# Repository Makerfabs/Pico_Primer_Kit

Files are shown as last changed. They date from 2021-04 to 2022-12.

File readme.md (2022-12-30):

# Pico(W) Primer Kit

```c++
/*
Version:		V1.8
Author:			Vincent
Create Date:	2021/4/16
Note:
	2022/12/30	V1.8 Edit Wiki Link
	2022/10/11 	V1.7 Add project11,12
	2022/10/8 	V1.6 Update project10
	2022/9/27 	V1.5 Add PicoW support, add new Mabee CO2
	2022/9/20 	V1.4 Fix dht11 bug.
	2021/7/27 	V1.3 Add WS2812
	2021/5/24 	V1.2 Change IR to Ultar distance sensor.
	2021/5/19 	V1.1 Add 7 display example with MaBee module.
	
*/
```

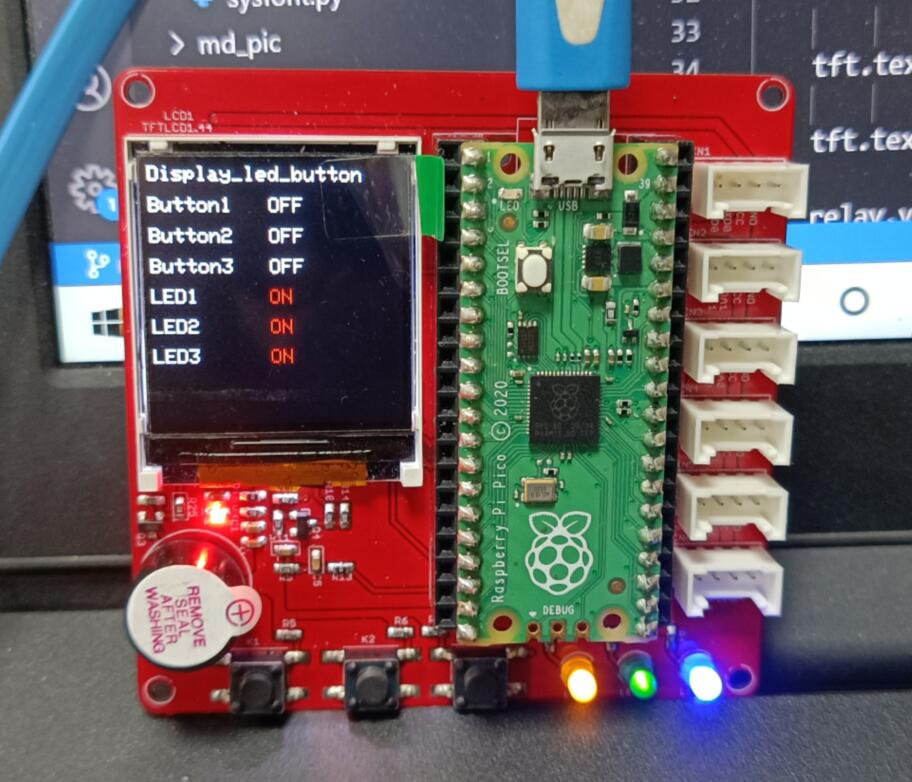
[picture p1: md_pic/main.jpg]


[toc]

# Makerfabs

[Makerfabs home page](https://www.makerfabs.com/)

[Makerfabs Wiki](https://wiki.makerfabs.com/)

# Pico(PicoW) Primer Kit
## Intruduce

### Product Link ：

[Pico Primer Kit for Raspberry PI](https://www.makerfabs.com/raspberry-pi-pico-primer-kit.html)

[Pico W Primer Kit for Raspberry PI](https://www.makerfabs.com/pico-w-primer-kit-for-raspberry-pi.html)

### Wiki Link : 

[Pico W_Primer_kit](https://wiki.makerfabs.com/Pico_W_Primer_Kit.html)

Pico Primer Kit is the development shield of Pi Pico. It has ST7735 color screen, 3 LED lights and 3 buttons. There are multiple SPI, I2C, UART, GPIO interfaces.
Kit contains a number of MBEE series modules. Such as potentiometer, DHT11, MPU6050, relay and other modules.

**Now that we have a new kit for Pico W, we have replaced the 8266 module with Mabee CO2.**

Most routines are compatible, the only differences are those related to WiFi.

## Feature

- RP2040 microcontroller chip designed by Raspberry Pi in the United Kingdom
- Dual-core Arm Cortex M0+ processor, the flexible clock running up to 133 MHz
- 264KB of SRAM, and 2MB of onboard Flash memory
- Castellated module allows soldering direct to carrier boards
- USB 1.1 with device and host support
- Low-power sleep and dormant modes
- Drag-and-drop programming using mass storage over USB
- 26 × multi-function GPIO pins
- 2 × SPI, 2 × I2C, 2 × UART, 3 × 12-bit ADC, 16 × controllable PWM channels
- Accurate clock and timer on-chip
- Temperature sensor
- Accelerated floating-point libraries on-chip
- 8 × Programmable I/O (PIO) state machines for custom peripheral support

### Front:

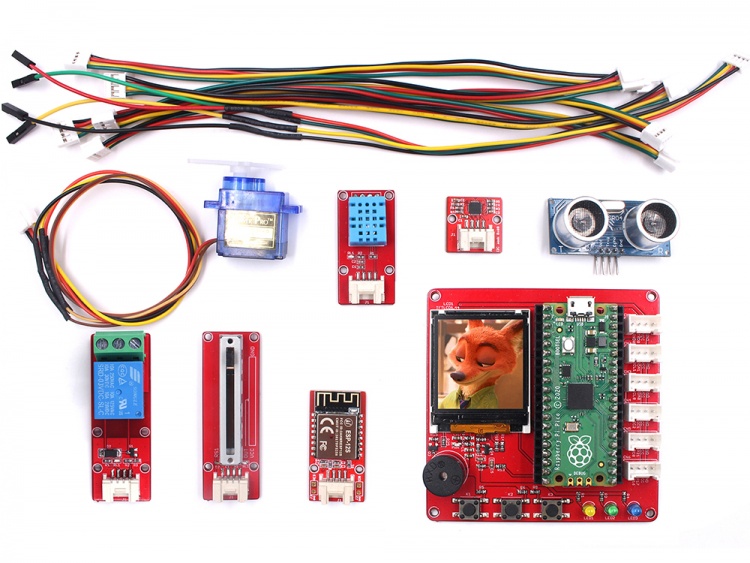
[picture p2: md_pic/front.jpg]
front


### Back:
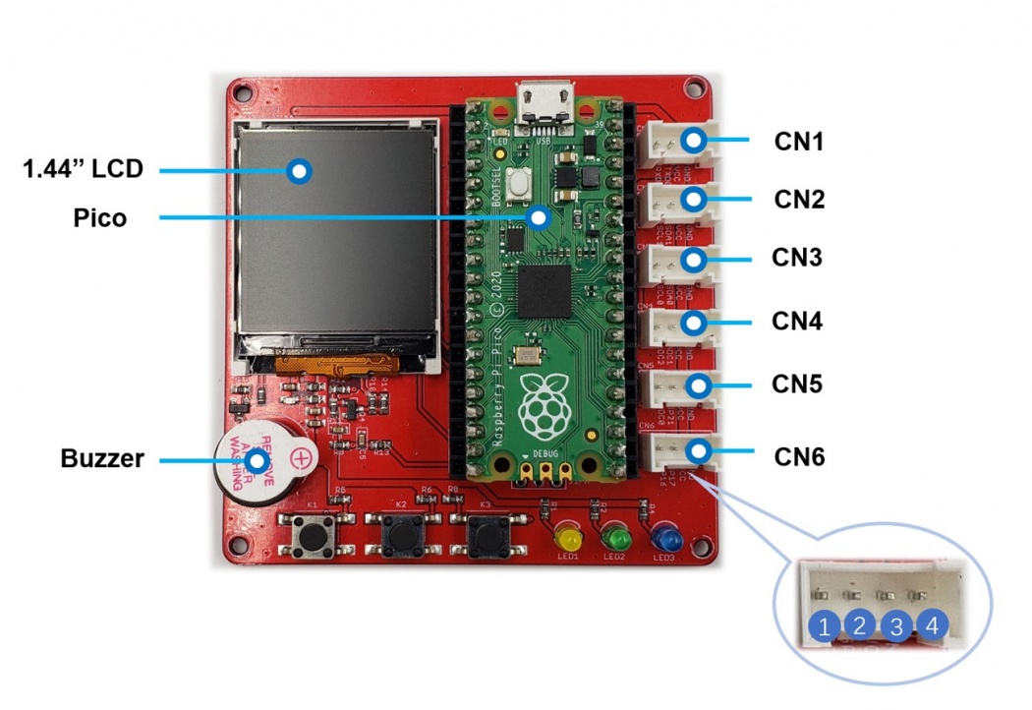
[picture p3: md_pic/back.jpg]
back


# Example
## Equipment list

- Pico Primer Kit
- Pi Pico
- MBee modules

## How To Use?

Attention, all code depends on MicroPython v1.19.1 on 2022-08-19

**Subsequent code may not run due to MicroPython version updates. We provide two firmware.**

- Pico		:	rp2-pico-20220618-v1.19.1.uf2

- PicoW	:	rp2-pico-w-20220819-unstable-v1.19.1-298-gc616721b1.uf2

Because PicoW MicroPython has not been officially released, so the driver of the sensor, subject to the Pico.

**If you have any questions，such as how to install the development board, how to download the code.**

**Please refer to :[Get Started with MicroPython on Raspberry Pi Pico](https://hackspace.raspberrypi.org/books/micropython-pico)**

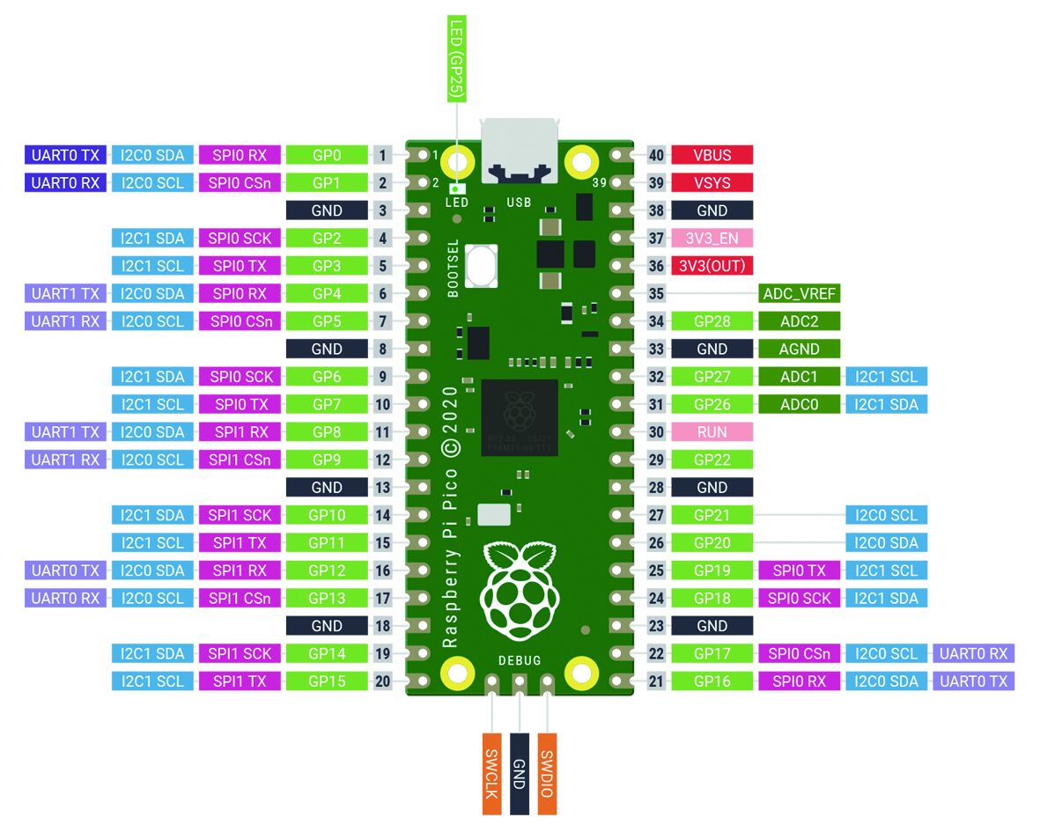
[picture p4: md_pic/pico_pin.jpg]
pin


## V1.2 Project

### project-1-display_led_button.py

Control onboard leds via buttons.
And display status on TFT screen.
Don't need any module

### project-2-leveling.py

Simple graphic level, read inclination angle with MPU6050.
Insert MaBee MPU6050 to CN3

### project-3-adc_display.py

The voltage value of the read slide potentimeter is displayed on the screen
Insert MaBee Slide Potentimeter to CN5

### project-4-weather_8266.py

Connect to WiFi through ESP8266 module and get the weather.
Insert MaBee 8266 to CN1
API from "api.openweathermap.org" is not stable, please try more and pay attention to the serial port information.

### project-5-temperature .py

The temperature and humidity are obtained through DHT11 and displayed on the screen
Insert MaBee DHT11 to CN6

### ~~project-6-ir_distance.py~~

~~The distance is captured by a Sharpir sensor and displayed on the screen~~
~~Insert SharpIR to CN5~~

### project-6-HC-SR04_distance.py

The distance is captured by a HC-SR04 Ultra sensor and displayed on the screen
Insert SharpIR to CN6

### project-7-servo_control.py

Use button control servo and MaBee relay
Insert Servo to CN6
Insert MaBee Relay to CN5

### project-8-ws2812.py
Insert WS2812 to CN6

### project-9-weather.py

Instead of Project 4 without 8266.

**Only for Pico W**

### project-10-CO2.py

Mabee CO2 message display and run a webserver.

Insert Mabee CO2 to CN3, sda to GPIO8, scl to GPIO9

Need change WiFi config in code.

```python
ssid = 'Makerfabs'
password = '20160704'
```

### project-11-thingspeak.py

A simple example is sending data to ThingSpeak. 

Please replace the Wifi information and Thingspeak interface with the user's own.

**Only for Pico W**

### project-12-PIR_detection.py

PIR induction Demo, when the sensor detects the human body after alarm.

## Other test file

All files starting with Test are used by engineers and are not guaranteed to be completely correct. 

But it has some reference value.

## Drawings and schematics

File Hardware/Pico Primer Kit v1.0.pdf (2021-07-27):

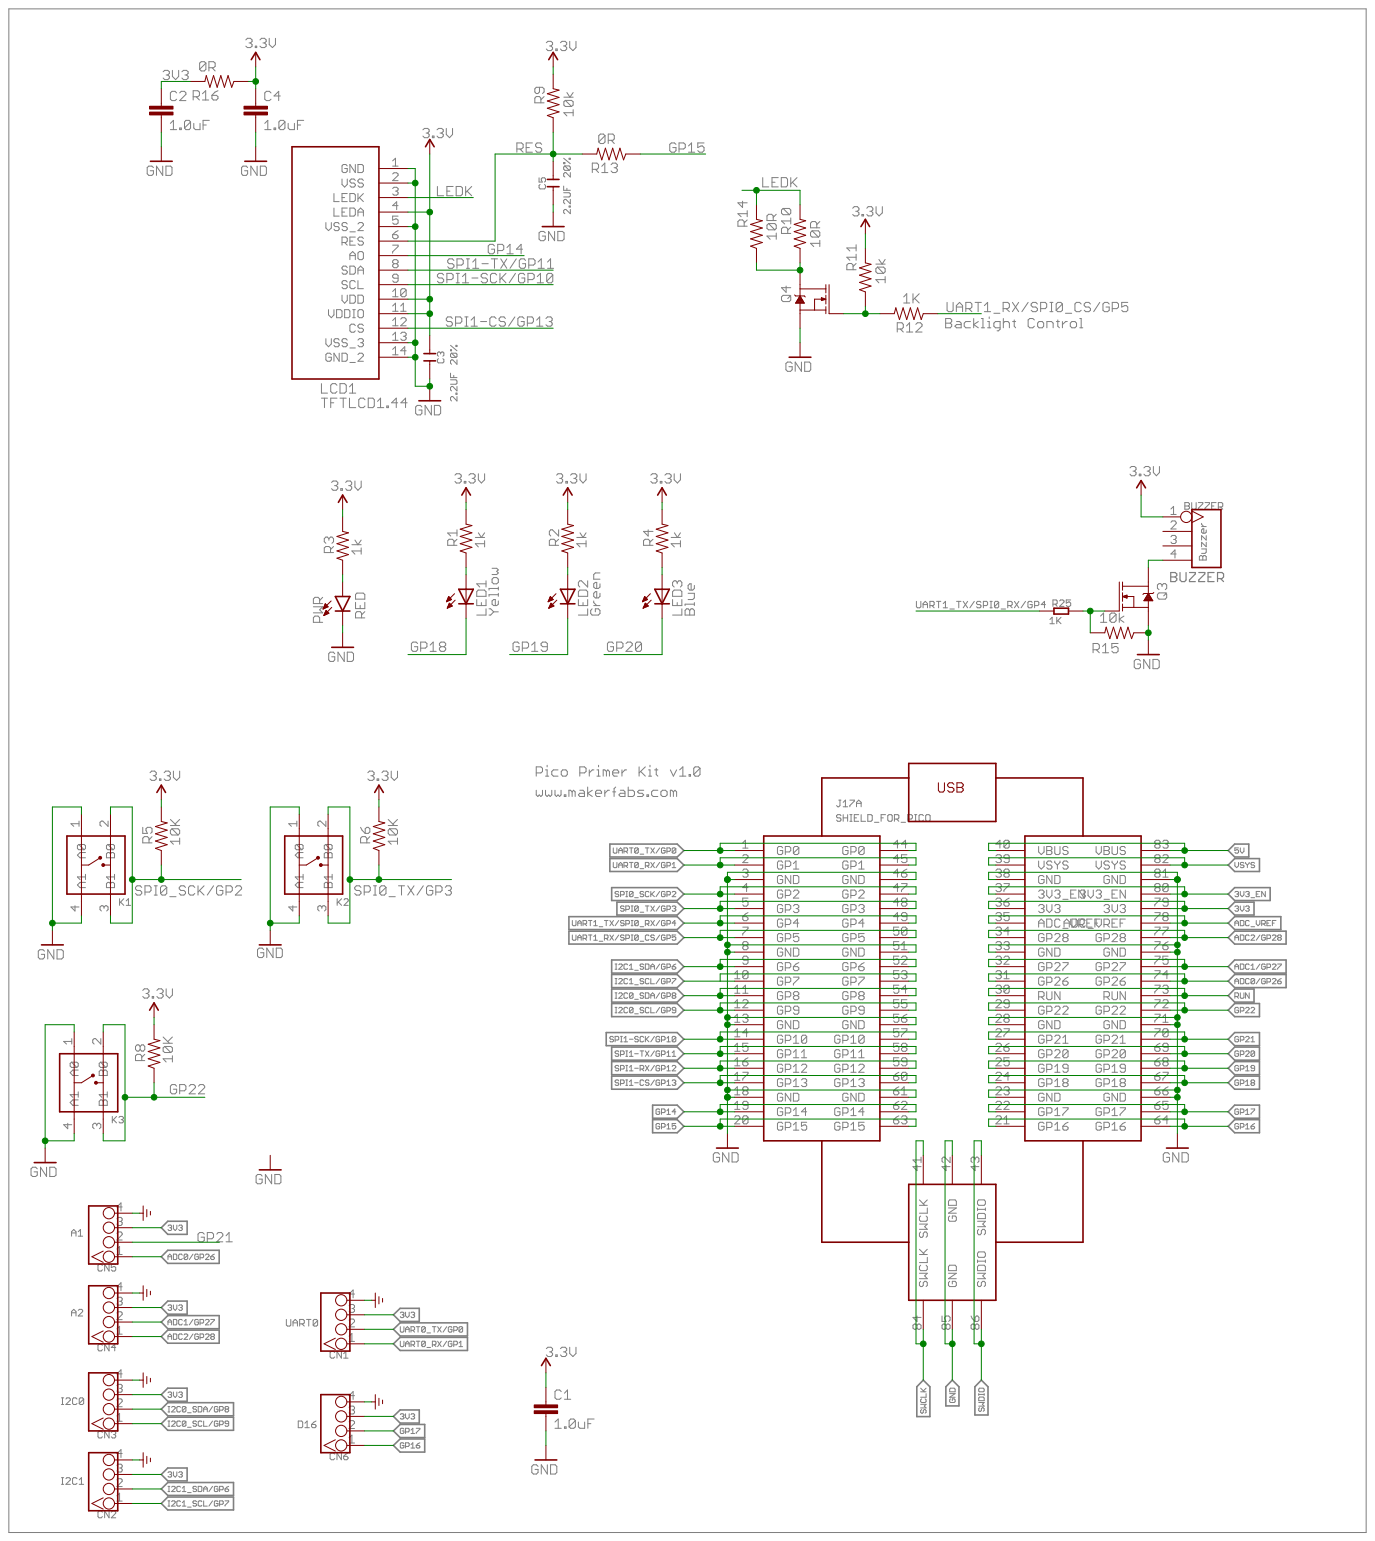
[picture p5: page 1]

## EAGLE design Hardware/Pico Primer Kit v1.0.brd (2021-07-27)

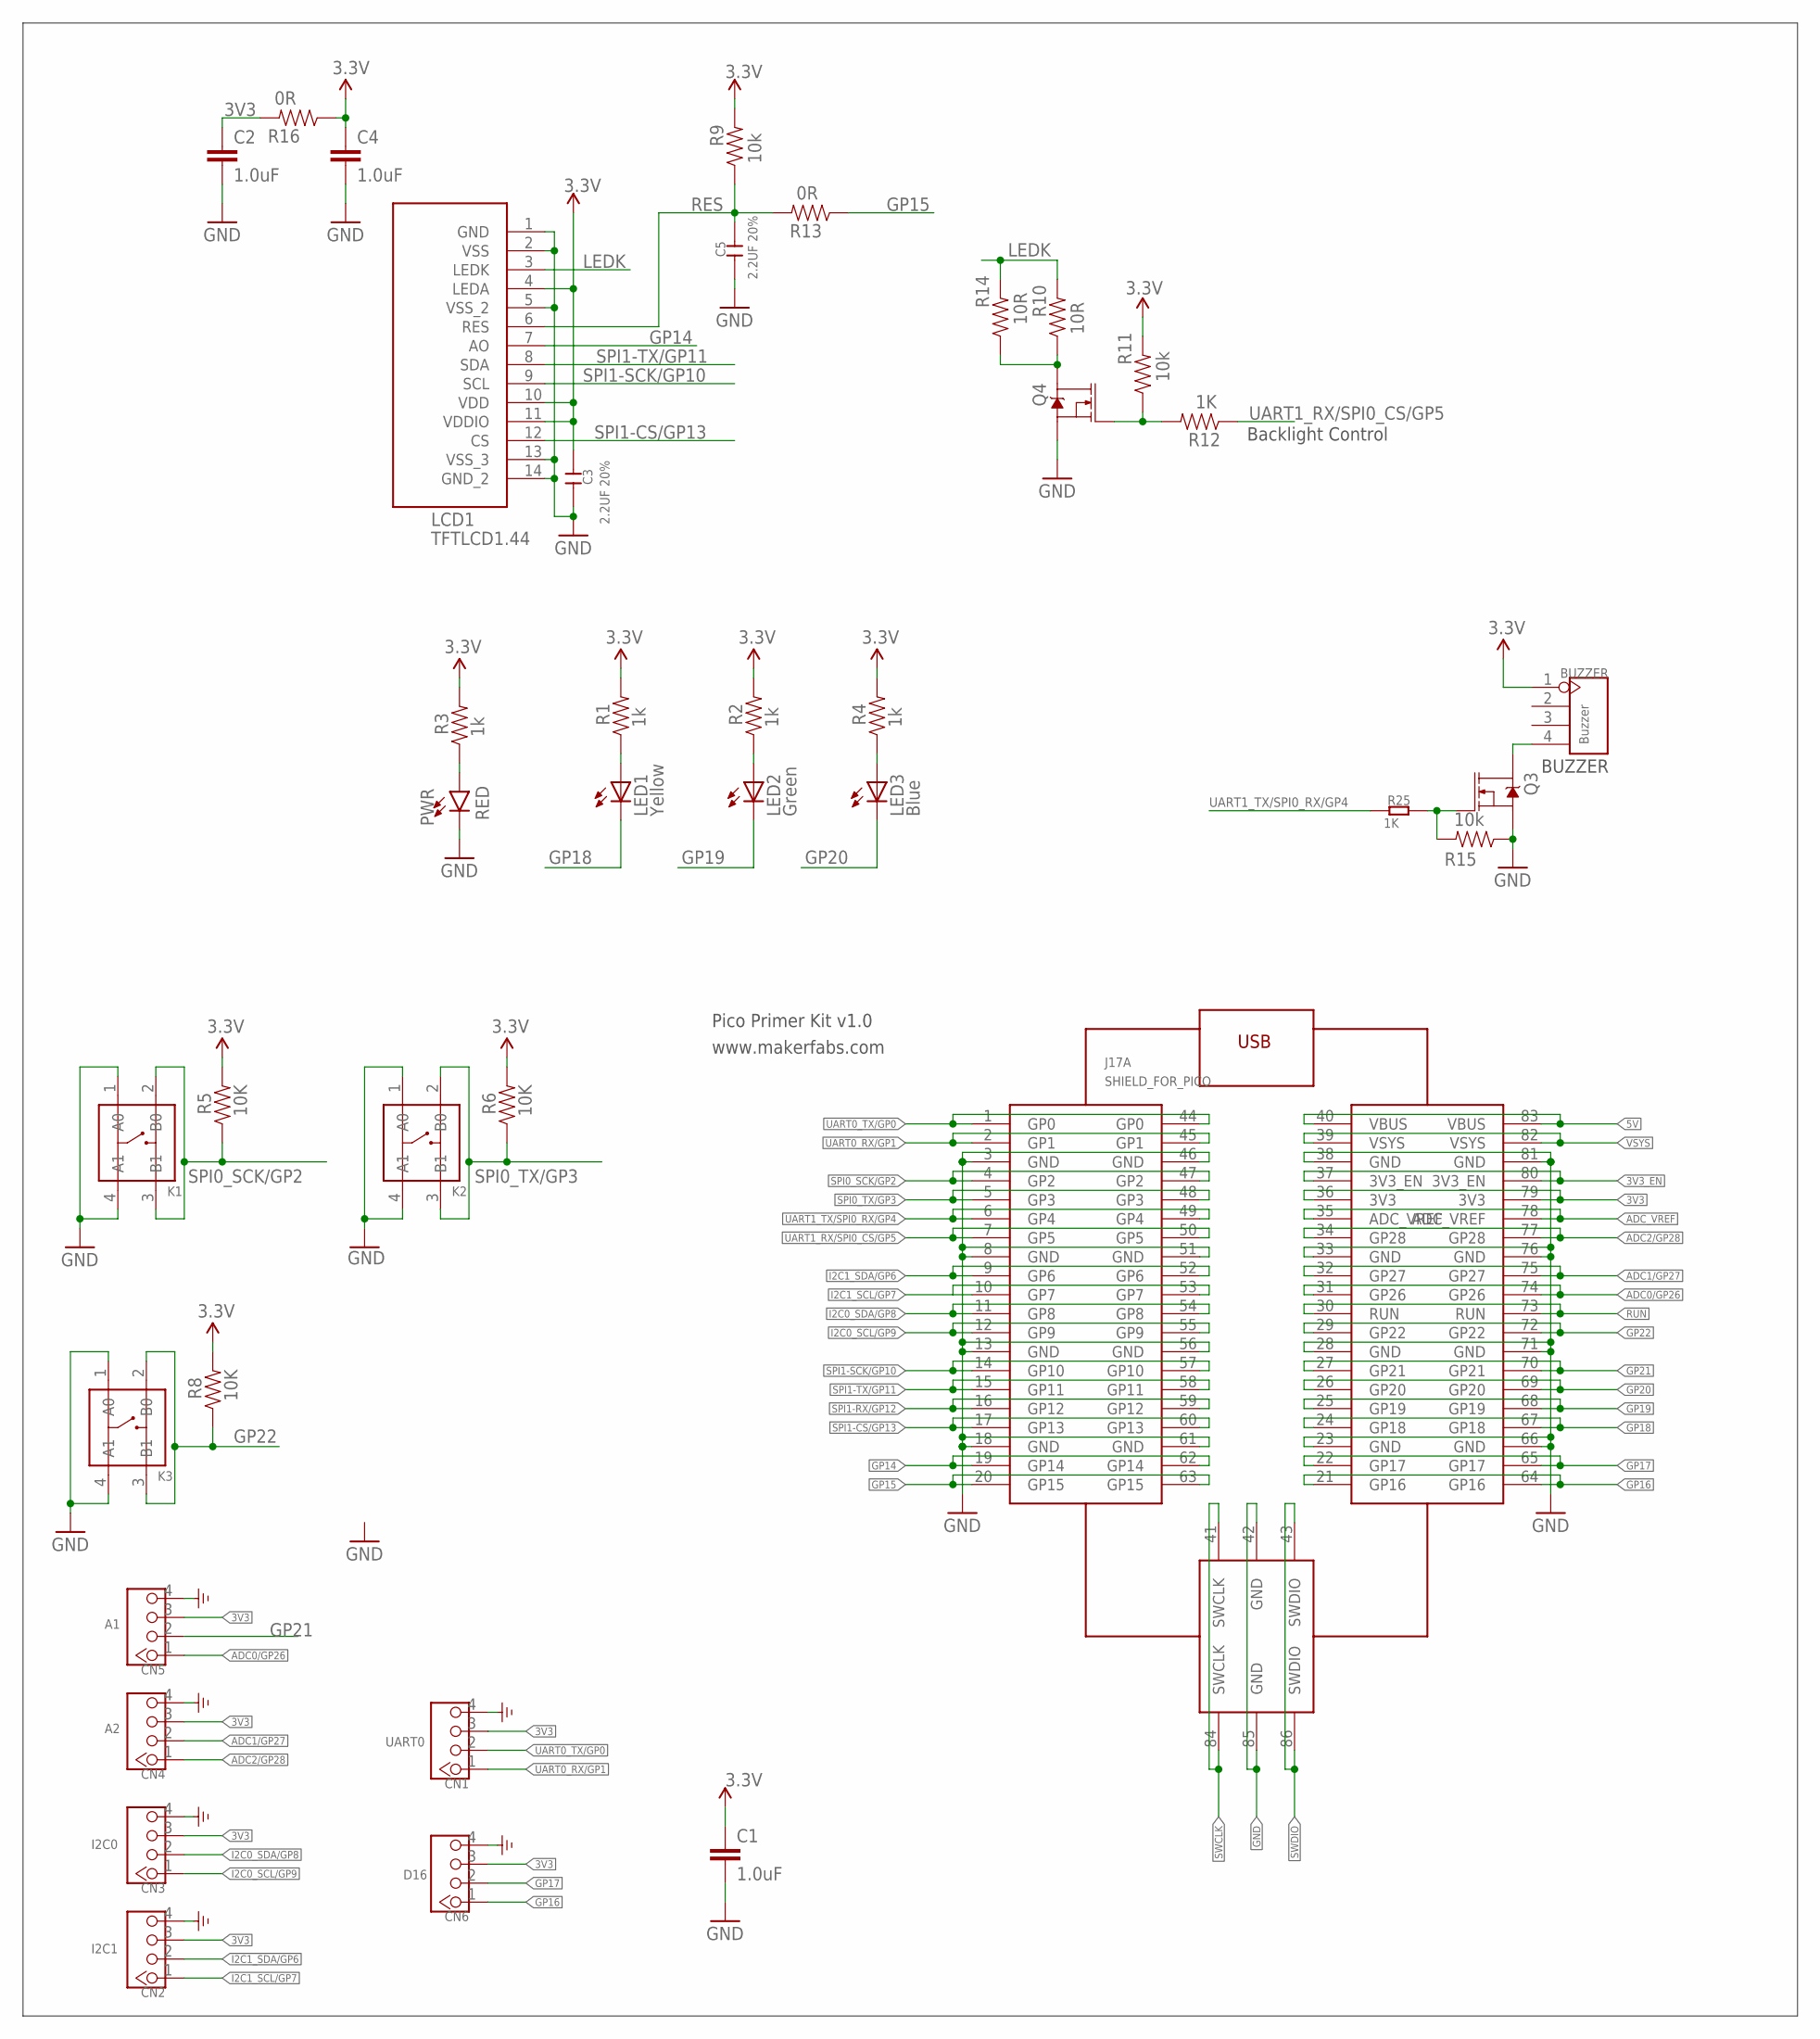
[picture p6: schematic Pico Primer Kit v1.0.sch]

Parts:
BUZZER: Buzzer; 4P-65/35ROUND
C1, C2, C4: 1.0uF; 0603
C3, C5: 2.2UF 20%; 0603
CN1: UART0; 4P-2.0
CN2: I2C1; 4P-2.0
CN3: I2C0; 4P-2.0
CN4: A2; 4P-2.0
CN5: A1; 4P-2.0
CN6: D16; 4P-2.0
J17A: SHIELD_FOR_PICO
K1, K2, K3: BUTTON-4P-3100010P1; 4P-SMD-6.0X6.0X5.0H
LCD1: TFTLCD1.44
LED1: Yellow; LED3MM
LED2: Green; LED3MM
LED3: Blue; LED3MM
PWR: RED; LED-0603
Q3, Q4: 220mA/50V/3.5Ω; SOT23-3
R1, R2, R3, R4: 1k; 0603
R5, R6, R8: 10K; 0603
R9, R11, R15: 10k; 0603
R10, R14: 10R; 0603
R12: 1K; 0603
R13, R16: 0R; 0603
R25: 1K; R0603

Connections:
3.3V: BUZZER.1, C1.1, C3.2, C4.1, LCD1.4 (LEDA), LCD1.10 (VDD), LCD1.11 (VDDIO), R1.2, R2.2, R3.2, R4.2, R5.2, R6.2, R8.2, R9.2, R11.2, R16.1
3V3: C2.1, CN1.3, CN2.3, CN3.3, CN4.3, CN5.3, CN6.3, J17A.36 (3V3), J17A.79 (3V3), R16.2
3V3_EN: J17A.37 (3V3_EN), J17A.80 (3V3_EN)
5V: J17A.40 (VBUS), J17A.83 (VBUS)
ADC0/GP26: CN5.1, J17A.31 (GP26), J17A.74 (GP26)
ADC1/GP27: CN4.2, J17A.32 (GP27), J17A.75 (GP27)
ADC2/GP28: CN4.1, J17A.34 (GP28), J17A.77 (GP28)
ADC_VREF: J17A.35 (ADC_VREF), J17A.78 (ADC_VREF)
GND: C1.2, C2.2, C3.1, C4.2, C5.1, CN1.4, CN2.4, CN3.4, CN4.4, CN5.4, CN6.4, J17A.3 (GND), J17A.8 (GND), J17A.13 (GND), J17A.18 (GND), J17A.23 (GND), J17A.28 (GND), J17A.33 (GND), J17A.38 (GND), J17A.42 (GND), J17A.46 (GND), J17A.51 (GND), J17A.56 (GND), J17A.61 (GND), J17A.66 (GND), J17A.71 (GND), J17A.76 (GND), J17A.81 (GND), J17A.85 (GND), K1.1 (A0), K1.4 (A1), K2.1 (A0), K2.4 (A1), K3.1 (A0), K3.4 (A1), LCD1.1 (GND), LCD1.2 (VSS), LCD1.5 (VSS_2), LCD1.13 (VSS_3), LCD1.14 (GND_2), PWR.C, Q3.2 (S), Q4.2 (S), R15.1
GP14: J17A.19 (GP14), J17A.62 (GP14), LCD1.7 (AO)
GP15: J17A.20 (GP15), J17A.63 (GP15), R13.1
GP16: CN6.1, J17A.21 (GP16), J17A.64 (GP16)
GP17: CN6.2, J17A.22 (GP17), J17A.65 (GP17)
GP18: J17A.24 (GP18), J17A.67 (GP18), LED1.K (C)
GP19: J17A.25 (GP19), J17A.68 (GP19), LED2.K (C)
GP20: J17A.26 (GP20), J17A.69 (GP20), LED3.K (C)
GP21: CN5.2, J17A.27 (GP21), J17A.70 (GP21)
GP22: J17A.29 (GP22), J17A.72 (GP22), K3.2 (B0), K3.3 (B1), R8.1
I2C0_SCL/GP9: CN3.1, J17A.12 (GP9), J17A.55 (GP9)
I2C0_SDA/GP8: CN3.2, J17A.11 (GP8), J17A.54 (GP8)
I2C1_SCL/GP7: CN2.1, J17A.10 (GP7), J17A.53 (GP7)
I2C1_SDA/GP6: CN2.2, J17A.9 (GP6), J17A.52 (GP6)
LEDK: LCD1.3 (LEDK), R10.2, R14.2
unnamed: LED1.A, R1.1
unnamed: PWR.A, R3.1
unnamed: Q4.3 (D), R10.1, R14.1
unnamed: Q4.1 (G), R11.1, R12.2
unnamed: LED2.A, R2.1
unnamed: LED3.A, R4.1
unnamed: BUZZER.4, Q3.3 (D)
unnamed: Q3.1 (G), R15.2, R25.2
RES: C5.2, LCD1.6 (RES), R9.1, R13.2
RUN: J17A.30 (RUN), J17A.73 (RUN)
SPI0_SCK/GP2: J17A.4 (GP2), J17A.47 (GP2), K1.2 (B0), K1.3 (B1), R5.1
SPI0_TX/GP3: J17A.5 (GP3), J17A.48 (GP3), K2.2 (B0), K2.3 (B1), R6.1
SPI1-CS/GP13: J17A.17 (GP13), J17A.60 (GP13), LCD1.12 (CS)
SPI1-RX/GP12: J17A.16 (GP12), J17A.59 (GP12)
SPI1-SCK/GP10: J17A.14 (GP10), J17A.57 (GP10), LCD1.9 (SCL)
SPI1-TX/GP11: J17A.15 (GP11), J17A.58 (GP11), LCD1.8 (SDA)
SWCLK: J17A.41 (SWCLK), J17A.84 (SWCLK)
SWDIO: J17A.43 (SWDIO), J17A.86 (SWDIO)
UART0_RX/GP1: CN1.1, J17A.2 (GP1), J17A.45 (GP1)
UART0_TX/GP0: CN1.2, J17A.1 (GP0), J17A.44 (GP0)
UART1_RX/SPI0_CS/GP5: J17A.7 (GP5), J17A.50 (GP5), R12.1
UART1_TX/SPI0_RX/GP4: J17A.6 (GP4), J17A.49 (GP4), R25.1
VSYS: J17A.39 (VSYS), J17A.82 (VSYS)

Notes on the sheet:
Pico Primer Kit v1.0
www.makerfabs.com
BUZZER
Backlight Control

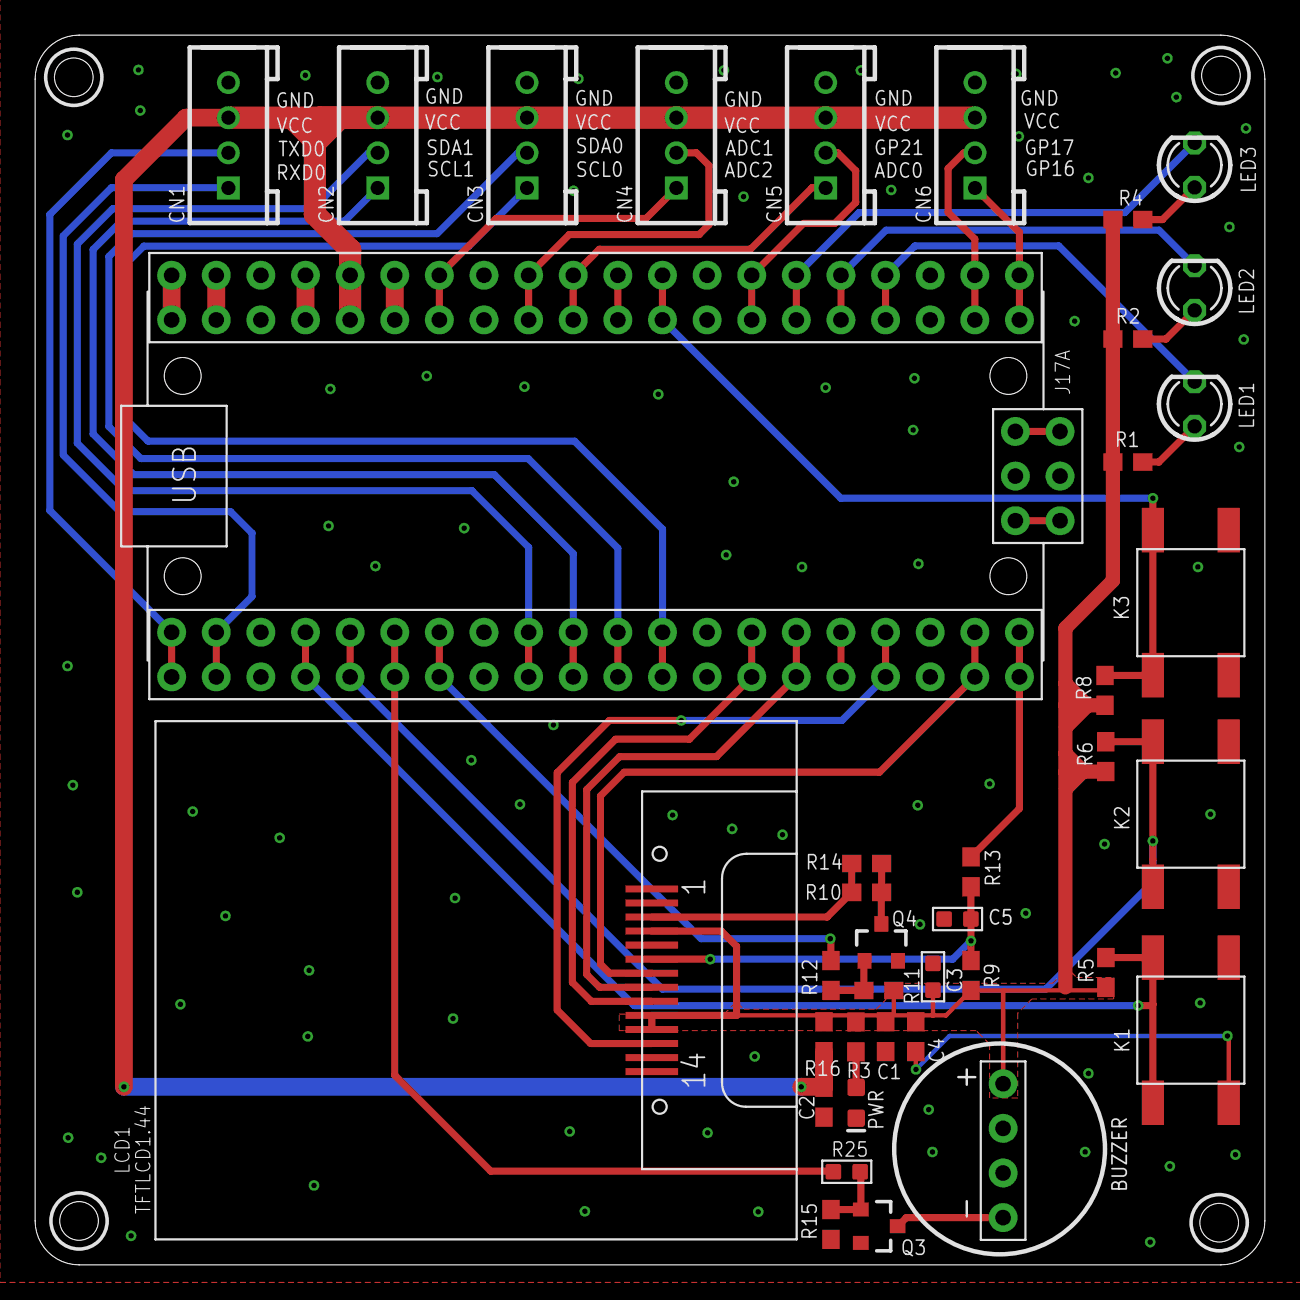
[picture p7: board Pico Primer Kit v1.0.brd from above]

Board: 2 copper layers, 70.0 x 70.0 mm, 40 parts (1 on the bottom side), 46 nets.

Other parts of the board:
U$1: MAKERFABS_0.3

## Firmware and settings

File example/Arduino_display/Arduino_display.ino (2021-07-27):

#include <Adafruit_GFX.h>    // Core graphics library
#include <Adafruit_ST7735.h> // Hardware-specific library for ST7735
#include <SPI.h>

#include "a1.h"
#include "pic1.h"
#include "pic2.h"

#define TFT_CS 13
#define TFT_RST 15 // Or set to -1 and connect to Arduino RESET pin
#define TFT_DC 14

#define SPI_MOSI 11
#define SPI_MISO 12
#define SPI_SCK 10

Adafruit_ST7735 tft = Adafruit_ST7735(TFT_CS, TFT_DC, TFT_RST);

void setup(void)
{
    Serial.begin(115200);
    Serial.print(F("Hello! ST77xx TFT Test"));

    SPI = MbedSPI(SPI_MISO, SPI_MOSI, SPI_SCK);

    // OR use this initializer (uncomment) if using a 1.44" TFT:
    tft.initR(INITR_144GREENTAB); // Init ST7735R chip, green tab

    Serial.println(F("Initialized"));

    tft.fillScreen(ST77XX_BLACK);
}

void loop()
{
    //Show logo
    tft.drawRGBBitmap(0, 0, a1, 128, 128);
    delay(3000);
    tft.drawRGBBitmap(0, 0, pic1, 128, 128);
    delay(3000);
    tft.drawRGBBitmap(0, 0, pic2, 128, 128);
    delay(3000);
}

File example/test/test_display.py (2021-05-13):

# Our supplier changed the 1.8" display slightly after Jan 10, 2012
# so that the alignment of the TFT had to be shifted by a few pixels
# this just means the init code is slightly different. Check the
# color of the tab to see which init code to try. If the display is
# cut off or has extra 'random' pixels on the top & left, try the
# other option!
# If you are seeing red and green color inversion, use Black Tab
# If your TFT's plastic wrap has a Black Tab, use the following:
#  tft.initR(INITR_BLACKTAB);   // initialize a ST7735S chip, black tab
# If your TFT's plastic wrap has a Red Tab, use the following:
# tft.initR(INITR_REDTAB);   // initialize a ST7735R chip, red tab
# If your TFT's plastic wrap has a Green Tab, use the following:
# tft.initR(INITR_GREENTAB); // initialize a ST7735R chip, green tab


from ST7735 import TFT
from sysfont import sysfont
from machine import SPI, Pin
import time
import math


spi = SPI(1, baudrate=20000000, polarity=0, phase=0,
          sck=Pin(10), mosi=Pin(11), miso=None)
# def __init__( self, spi, aDC, aReset, aCS) :
tft = TFT(spi, 14, 15, 13)

tft.initg()
tft.rgb(True)


def testlines(color):
    tft.fill(TFT.BLACK)
    for x in range(0, tft.size()[0], 6):
        tft.line((0, 0), (x, tft.size()[1] - 1), color)
    for y in range(0, tft.size()[1], 6):
        tft.line((0, 0), (tft.size()[0] - 1, y), color)

    tft.fill(TFT.BLACK)
    for x in range(0, tft.size()[0], 6):
        tft.line((tft.size()[0] - 1, 0), (x, tft.size()[1] - 1), color)
    for y in range(0, tft.size()[1], 6):
        tft.line((tft.size()[0] - 1, 0), (0, y), color)

    tft.fill(TFT.BLACK)
    for x in range(0, tft.size()[0], 6):
        tft.line((0, tft.size()[1] - 1), (x, 0), color)
    for y in range(0, tft.size()[1], 6):
        tft.line((0, tft.size()[1] - 1), (tft.size()[0] - 1, y), color)

    tft.fill(TFT.BLACK)
    for x in range(0, tft.size()[0], 6):
        tft.line((tft.size()[0] - 1, tft.size()[1] - 1), (x, 0), color)
    for y in range(0, tft.size()[1], 6):
        tft.line((tft.size()[0] - 1, tft.size()[1] - 1), (0, y), color)


def testfastlines(color1, color2):
    tft.fill(TFT.BLACK)
    for y in range(0, tft.size()[1], 5):
        tft.hline((0, y), tft.size()[0], color1)
    for x in range(0, tft.size()[0], 5):
        tft.vline((x, 0), tft.size()[1], color2)


# def testgamerects(color):
 #   tft.fill(TFT.WHITE) ## How is this screen not GameEngine

  #  for i in range(game.height):
   #     for j in range(game.width):
        # OK need shapes in gameEngine
       #    TFT.rect(screen, GRAY, [
        #                    game.x + game.zoom * j, game.y + game.zoom * i, game.zoom, game.zoom], 1)
        #   if game.field[i][j] > 0:
        #    TFT.rect(screen, colors[game.field[i][j]],
        #                    [game.x + game.zoom * j + 1, game.y + game.zoom * i + 1, game.zoom - 2, game.zoom - 1])


def testdrawrects(color):
    tft.fill(TFT.BLACK)
    for x in range(0, tft.size()[0], 6):
        tft.rect((tft.size()[0]//2 - x//2, tft.size()
                  [1]//2 - x/2), (x, x), color)


def testfillrects(color1, color2):
    tft.fill(TFT.BLACK)
    for x in range(tft.size()[0], 0, -6):
        tft.fillrect((tft.size()[0]//2 - x//2,
                      tft.size()[1]//2 - x/2), (x, x), color1)
        tft.rect((tft.size()[0]//2 - x//2, tft.size()
                  [1]//2 - x/2), (x, x), color2)


def testfillcircles(radius, color):
    for x in range(radius, tft.size()[0], radius * 2):
        for y in range(radius, tft.size()[1], radius * 2):
            tft.fillcircle((x, y), radius, color)


def testdrawcircles(radius, color):
    for x in range(0, tft.size()[0] + radius, radius * 2):
        for y in range(0, tft.size()[1] + radius, radius * 2):
            tft.circle((x, y), radius, color)


def testtriangles():
    tft.fill(TFT.BLACK)
    color = 0xF800
    w = tft.size()[0] // 2
    x = tft.size()[1] - 1
    y = 0
    z = tft.size()[0]
    for t in range(0, 15):
        tft.line((w, y), (y, x), color)
        tft.line((y, x), (z, x), color)
        tft.line((z, x), (w, y), color)
        x -= 4
        y += 4
        z -= 4
        color += 100


def testroundrects():
    tft.fill(TFT.BLACK)
    color = 100
    for t in range(5):
        x = 0
        y = 0
        w = tft.size()[0] - 2
        h = tft.size()[1] - 2
        for i in range(17):
            tft.rect((x, y), (w, h), color)
            x += 2
            y += 3
            w -= 4
            h -= 6
            color += 1100
        color += 100


def tftprinttest():
    tft.fill(TFT.BLACK)
    v = 30
    tft.text((0, v), "Hello World!", TFT.RED, sysfont, 1, nowrap=True)
    v += sysfont["Height"]
    tft.text((0, v), "Hello World!", TFT.YELLOW, sysfont, 2, nowrap=True)
    v += sysfont["Height"] * 2
    tft.text((0, v), "Hello World!", TFT.GREEN, sysfont, 3, nowrap=True)
    v += sysfont["Height"] * 3
    tft.text((0, v), str(1234.567), TFT.BLUE, sysfont, 4, nowrap=True)
    time.sleep_ms(1500)
    tft.fill(TFT.BLACK)
    v = 0
    tft.text((0, v), "Hello World!", TFT.RED, sysfont)
    v += sysfont["Height"]
    tft.text((0, v), str(math.pi), TFT.GREEN, sysfont)
    v += sysfont["Height"]
    tft.text((0, v), " Want pi?", TFT.GREEN, sysfont)
    v += sysfont["Height"] * 2
    tft.text((0, v), hex(8675309), TFT.GREEN, sysfont)
    v += sysfont["Height"]
    tft.text((0, v), " Print HEX!", TFT.GREEN, sysfont)
    v += sysfont["Height"] * 2
    tft.text((0, v), "Sketch has been", TFT.WHITE, sysfont)
    v += sysfont["Height"]
    tft.text((0, v), "running for: ", TFT.WHITE, sysfont)
    v += sysfont["Height"]
    tft.text((0, v), str(time.ticks_ms() / 1000), TFT.PURPLE, sysfont)
    v += sysfont["Height"]
    tft.text((0, v), " seconds.", TFT.WHITE, sysfont)
    tft.fill(TFT.BLACK)
    tft.text((0, 0), "Lorem ipsum dolor sit amet, consectetur adipiscing elit. Curabitur adipiscing ante sed nibh tincidunt feugiat. Maecenas enim massa, fringilla sed malesuada et, malesuada sit amet turpis. Sed porttitor neque ut ante pretium vitae malesuada nunc bibendum. Nullam aliquet ultrices massa eu hendrerit. Ut sed nisi lorem. In vestibulum purus a tortor imperdiet posuere. ", TFT.WHITE, sysfont, 1)
    time.sleep_ms(1000)

    # def rect( self, aStart, aSize, aColor ) :
    '''Draw a hollow rectangle.  aStart is the smallest coordinate corner
       and aSize is a tuple indicating width, height.'''


def testdrawarects(color):
    tft.fill(TFT.BLACK)

    tft.rect((tft.size()[0]//2, tft.size()
              [1]//2), (50, 100), color)

    tft.rect((1, 1), (127, 159), TFT.RED)
    print(str(tft.size()[0]//2))
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

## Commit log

2021-06-07 add Arduino display demo
2021-06-07 create hardware
    [Pico Primer Kit v1.0.brd, Pico Primer Kit v1.0.sch]
2022-01-06 Fix Change the string matching mode to regular expression matching.
    [project-4-weather_8266.py]
2022-08-25 Add pico W support

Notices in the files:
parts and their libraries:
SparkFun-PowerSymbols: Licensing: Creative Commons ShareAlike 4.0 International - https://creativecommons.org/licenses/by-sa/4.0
